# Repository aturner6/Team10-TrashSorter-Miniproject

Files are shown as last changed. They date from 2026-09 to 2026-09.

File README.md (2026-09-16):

# 03-Miniproject-2026-27

This is a repo for a multi-disciplinary mini-project for a
small team of EEs and ME. The mini-project is described in the
course assignment. You should tailor this repo based on your team
composition, roles, and the tasks at hand.

Complete the project documentation in your Miniproject repo including:
Project summary (as .md) including 
Description of device 
Photo(s) of device
Description of how to use your device
Record a link to your device in operation (< 10s) and link to file stored in your team google team folder under /video
References to any source materials adopted in the project
Project support documents
Flowcharts and or/state charts of system 
Schematic of device (no fritzing please) 
Mechanical design and CAD drawings/STLs of enclosure (if MEs on team)
Code folder including embedded code comments
Simple readme.md in each subfolder

# Project Summary 

This device is a self-contained meeting timer that runs MicroPython on a Seeed XIAO ESP32-S3. The countdown begins after the user uses two tactile buttons to choose a predetermined time (15, 20, 25, or 30 minutes). Three status LEDs (powered with PWM for a pulsating effect) show the device's current condition, and a stepper motor powers an actual clock hand that scrolls down as time passes.

# Description of the device

* Microcontroller: Seeed XIAO ESP32-S3
* Motor: 28BYJ-48 5-wire, 4-phase unipolar stepper, driven through an L293D H-bridge (wave-pulse stepping, one coil energized at a time), moving a popsicle-stick clock hand to show time remaining
* Inputs: two tactile pushbuttons (GPIO5, GPIO6)
* Outputs: three PWM-driven LEDs: red (GPIO7), blue (GPIO8), green (GPIO9), each pulsed at a ~1s duty-cycle rate

# Photo of device 
IMG_3915-preview

# How to operate
Connect and turn on the power. The blue LED will then illuminate. Select the Modes 15, 20, 25, and 30 (min) which are cycled by the left button (Button 1). The timer can be started or stopped by pressing the right button (Button 2). Timer moves clockwise (CW) until it hits the set time, then resets back to start — until Button 2 is pressed again to change mode.\
LED states: Red indicates the time is up, Green indicates the timer is active, and Blue indicates cycling (mode choose).
# Demo video
  [Demo Google Drive Video](https://drive.google.com/file/d/13cO3BlyUWwyqgb_B9XeeHkqI3Kim0GOf/view?usp=drive_link)
# References 
Reference we used for PWM LED [LinuxHint](https://linuxhint.com/pwm-esp32-micropython-thonny-ide/)

# Flowchart of the system
The flow chart of the system is [State Diagram](docs/state-flow/Mini_Project_State_Diagram.drawio.pdf) — viewable PDF.
# Schematic of the device
The schematic chart of the system is [Schematic Chart](docs/hardware/electrical/MINIPROJECTDIAGRAM.pdf) — viewable PDF.
# Mechanical design and CAS drawings/STLs of enclosure
All the mechanical designs and STL files are in [Mechanical](docs/hardware/mechanical)

# Code folder

The code folder is in [Firmware](docs/firmware)

---

## Team

| Role | Named Members |
|---|---|
| Mechanical Engineering | John |
| Electrical Engineering | Adina, Rebecca, Richard, Carlos |

---

## Repository Structure

```
.
├── firmware/          # Micro source code
├── hardware/
│   ├── electrical/    # Schematics, wiring diagrams, and BOM
│   └── mechanical/    # Enclosure CAD files and fabrication notes
└── docs/              # Project documentation 
```

---

## Hardware

| Component | Description|
|---|--- |
| Seeed XIAO ESP32-S3, pre-soldered |Microcontroller for the clock|
| Multi-color LED |Visual indicator of status|
| Breadboard |Used for connections of all other components. |
| Tactile breadboard switch |One button cycles time duration, another starts and stops|	
 | 220-ohm resistor |adds resistance to circuit|
 | Battery holder, 3x AAA cells |powers the timer|
 | Stepper motor |moves the handles in steps for timer|
 | Motor driver (L293D) |6 step control|
 | Jumper wire kit |used to connect all the components on breadboard|

---

## Team Responsibilities 
Any discipline can do any role here -- you make the assigments. 

### Mechanical oriented - John Colcha
- Design the enclosure 
- Fabricate the enclosure (3-D print or laser-cut)
- Document the assembly process 

### Electrical oriented - Carlos Rivas, Adina Turner, Richard Huang
- Produce the breadboard schematic - Adina Turner
- Summarize the bill of materials - Carlos Rivas
- Wire the circuit on the breadboard, verify that the components are assembled correctly, validate the voltage levels - Adina Turner
- Develop flowchart for the time device - Richard Huang

### Computer oriented - Rebecca Brautigam, Carlos Rivas
- Design the software based on the required functionality - Rebecca Brautigam
- Develop MicroPython code and firmware - Rebecca Brautigam
- Flash and test the firmware on the target micro - Rebecca Brautigam
- Document the project on the repo and record 10 second video - Carlos Rivas

## Deliverables

- [ ] Functional MicroPython firmware
- [ ] Completed breadboard assembly per schematic
- [ ] Fabricated and assembled enclosure (if MEs on team)
- [ ] Documentation in this repository
- [ ] Video recording demonstrating required function (stored in google drive)

## Contribution Workflow

We want each team member to contribute work products and to host these
including documentation in the repo with version control (software,
firmware, schematics, BOMs, CAD models, etc.) All can be managed in
the repo with version control.

1. Establish that each team member has properly set up Git/GitHub Desktop
2. Decompose the project into units to assign to each named team member 
3. From the team repo, create a branch from `main` named `<role>/<feature>` (e.g., `me/case`) to capture work artifacts 
4. Fetch the branch to the local laptop
5. Each team member does their work and produces work artifacts and commits these changes to the branch
6. Commit changes with descriptive messages
7. Open a pull request and request review from at least one other team member
8. Merge to main after approval

When performed properly, this workflow leads to an organized set of
work products that are developed concurrently and collaboratively with
version control. This includes the products themselves (e.g.,
firmware, CAD, schematics, etc.) and the associated documentation

Don't know how to do this? Ask your ECE teammates, GSTs, instructors, or AI. 

---

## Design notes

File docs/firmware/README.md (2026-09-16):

# Code README

## Contents
The MicroPython source for the meeting timer was uploaded to the Seeed XIAO ESP32-S3 via Thonny.

Handles the three device states (picking preset, running, time's up)
Drives the 28BYJ-48 stepper (via the L293D H-bridge) to move the clock hand as time elapses
Reads the two tactile buttons (GPIO5, GPIO6) for preset selection and start/cancel control
Drives the three status LEDs (GPIO7 red, GPIO8 blue, GPIO9 green) with PWM for the pulsing effect

Each function and the pin mapping are explained by inline comments in the code. For complete operating instructions  see the root README.md and the state chart in ../docs/.

---

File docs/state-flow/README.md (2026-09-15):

# Meeting Timer State Flow Diagram

Documents the Ready, Running, Resetting, and Finished states,
including B1 preset selection, B2 start/reset, motor return,
and LED behavior. The diagram retains its original layout,
colors, fonts, and short wording.

- [Mini_Project_State_Diagram.drawio](Mini_Project_State_Diagram.drawio) — editable diagram.
- [Mini_Project_State_Diagram.drawio.pdf](Mini_Project_State_Diagram.drawio.pdf) — viewable PDF.

## Code reference

Matches [firstDraft.py at main commit 19f7ae3](https://github.com/aturner6/Team10-TrashSorter-Miniproject/blob/19f7ae3731c46b1a6b27202ce7752f3b77c4afbd/docs/firmware/firstDraft.py), reviewed September 15, 2026.

- B1 selects the next preset only in Ready, while the hand is not returning.
- B2 starts from Ready. While running, finished, or returning, B2 resets the selected duration and returns the hand if needed.
- Resetting returns to Ready when the hand reaches its starting position. If no return is needed, reset goes directly to Ready.
- Ready and Resetting use steady blue; Running pulses green; Finished pulses red.
- At completion, the hand returns and stops, but the timer stays Finished with red pulsing until B2 resets it.
- There is no pause/resume behavior in this code.

The current code uses **15/20/25/30 seconds**; the minute-based presets are commented out. The diagram labels seconds to match the implementation. The assignment requires minutes, so the team must finalize timing and then update both diagram files if that changes.

Validation: checked state transitions against the referenced source, verified the draw.io structure, and visually checked the regenerated PDF. Physical timing, motor direction, LED wiring, and hardware behavior still require team verification.

Related task: Issue #2 — Flowstate Chart to Assess Operations.

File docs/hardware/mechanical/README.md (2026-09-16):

## CAD Models and Components README
<br> <br>
<div align="center">

### Ideation and Initial Sketches
Before moving into SolidWorks, the initial concepts and dimensions were mapped out by hand. These sketches highlight the early brainstorming process for the enclosure's overall footprint, internal clearances for the breadboard, and the structural ideas for the stepper motor holder and tactile button attachments. 

<br>



<br>
<br>



</div>

<div align= "center">
  
  <br> <br>
  
## From Concept to CAD: SolidWorks Implementation
  <br> <br>
Using the dimensions and concepts mapped out in the initial sketches, the final components were modeled in SolidWorks. The isometric views below show the exact geometry used to 3D print the enclosure, incorporating the required motor mounts and external USB-C pathways.

<br>


<br>
<br>
This component serves as the enclosure lid and the timer's primary display surface, featuring a central clearance hole for the motor shaft and the indicator assembly.
<br>
<br>
</div>

<div align= "center">

<br> 
<br>
This forms the primary physical housing for the microcontroller, driver board, and wiring. It features a specific rectangular cutout on the side wall to provide the required pathway for the external USB-C cable
<br> 
<br>
</div>

# Figure A:
<div align+"center">

<br>
<br>

</div>

# Figure B:
<div align="center">

</div>

<div align="center">
<br>
As shown in Figures A and B, these parts serve as the physical interface for the timer. This component acts as the outer structural attachment for the tactile button. It mounts to the main enclosure and provides a precise  guide for the button stud to travel through smoothly.
<br>
<br>
</div>

<div align="center">

<br>
<br>
This bracket secures the stepper motor in place. Its side tabs allow it to be fastened firmly to the enclosure, fulfilling the required physical motor mount specification.
<br>
<br>
</div>

<div align="center">

<br>
<br>
The cylindrical sleeve features an internal keyed geometry design to mate with the flat edges of the stepper motor's shaft, ensuring the rotational torque is transferred to the clock hand without slipping.
<br>
<br>
</div>

<div align="center">

<br>
<br>
This is the physical plunger that the user presses. It rests inside the housing and makes direct contact with the tactile buttons on the board to input the 15, 20, 25, or 30-minute timer preset.
<br>
<br>
</div>

For details of the project, see the root README.md.

---

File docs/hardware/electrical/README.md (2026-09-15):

# Project Documentation

Electrical design files for the meeting timer.
Schematic of the XIAO ESP32-S3, L293D H-bridge driver, stepper motor, LEDs, and buttons

Bill of Materials (see xlsx file for links)

| Qty | Component | Part No. | Unit Price | Total | Vendor |
|---|---|--- | --- | --- |----- |
| `6 (per student)` | Seeed XIAO ESP32-S3, pre-soldered |1597-102010634-ND|$8.49|$50.94|Digikey|
| `1 (per student)` | Multi-color LED |1830-1014-ND|$0.59|$0.59|Digikey|
| `1 (per student)` | Breadboard |1188-BREADBOARD-1-ND|$2.05|$2.05|Digikey|
| `2 (per student)` | Tactile breadboard switch |EG2533CT-ND|	$0.20|$0.40|Digikey|
| `3 (per student)` | 220-ohm resistor |CF14JT220RCT-ND|$0.013|$0.04|Digikey|
| `1 (per team)` | Battery holder, 3x AAA cells |1428-1151-ND|$1.95|$1.95|Digikey|
| `1 (per team)` | Stepper motor |1188-SM-5VDC-DRV-ND|$2.93|$2.93|Digikey|
| `1 (per team)` | Motor driver (L293D) |5536-L293DN-ND|$1.73|$1.73|Digikey|
| `1 (per team)` | Jumper wire kit |BKWK-3-ND|$5.60|$5.60|Digikey|
| Total |  |||$66.24||

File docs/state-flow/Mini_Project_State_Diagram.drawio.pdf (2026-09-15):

EC463 / MINI-PROJECT

# Meeting timer — State diagram

Two buttons • Presets: 15 → 20 → 25 → 30 → 15 seconds (current code)

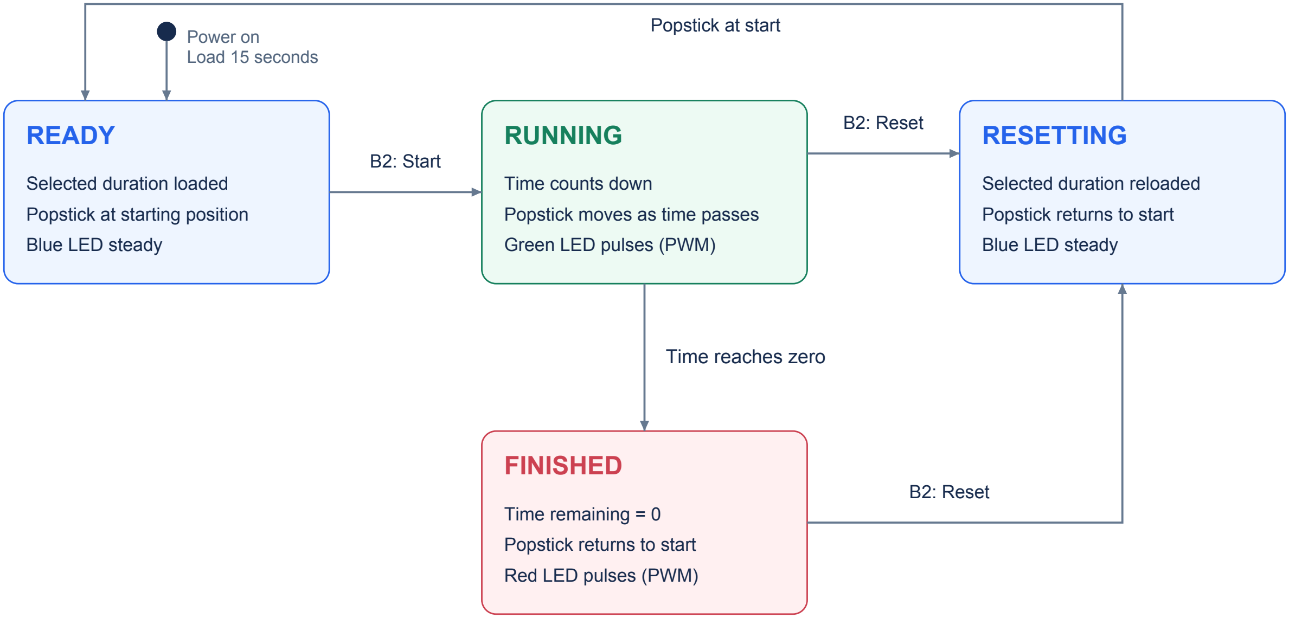
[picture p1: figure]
READY; Selected duration loaded; Popstick at starting position; Blue LED steady; RUNNING; Time counts down; Popstick moves as time passes; Green LED pulses (PWM); RESETTING; Selected duration reloaded; Popstick returns to start; FINISHED; Time remaining = 0; Red LED pulses (PWM); Power on Load 15 seconds; B2: Start; B2: Reset; Popstick at start; Time reaches zero

B1: MODE — applies in Ready only

### Next preset → reload time → stay Ready (no popstick movement)

Buttons: B1 selects only in Ready. B2 resets during return; if the hand is already at start, reset goes straight to Ready.

Finished: hand returns, then stops; red keeps pulsing until B2 resets. Startup: hand assumed at start.

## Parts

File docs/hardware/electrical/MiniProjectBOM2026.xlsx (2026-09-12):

Index | Distribution | Description | Part No. | QTY | Unit | Total | Vendor | URL | Alt source | Alt URL
1 | Per student | Seeed XIAO ESP32S3 pre-soldered | 1597-102010634-ND | 6 | 8.49 | 50.94 | Digikey | https://www.digikey.com/en/products/detail/seeed-technology-co-ltd/102010634/26553885 | Seeed (CA) | https://www.seeedstudio.com/Seeed-Studio-XIAO-ESP32S3-Pre-Soldered-p-6334.html
2 | Per student | Multi-color LED | 1830-1014-ND | 1 | 0.59 | 0.59 | Digikey | https://www.digikey.com/en/products/detail/inolux/INL-5TB4URGB60/7604616
3 | Per student | Breadboard | 1188-BREADBOARD-1-ND | 1 | 2.05 | 2.05 | Digikey | https://www.digikey.com/en/products/detail/olimex-ltd/BREADBOARD-1/21662422
4 | Per student (2) | Tactile breadboard switch | EG2533CT-ND | 2 | 0.20452 | 0.40904 | Digikey | https://www.digikey.com/en/products/detail/e-switch/TL59AF160Q/390534
5 | Per student (3) | Resistors 220 ohm | CF14JT220RCT-ND | 3 | 0.01258 | 0.03774 | Digikey | https://www.digikey.com/en/products/detail/CF14JT220R/CF14JT220RCT-ND/1830334
6 | Per team | Battery holder 3 AAA cells | 1428-1151-ND | 1 | 1.95 | 1.95 | Digikey | https://www.digikey.com/en/products/detail/adafruit-industries-llc/727/5353611
7 | Per team | Stepper motor | 1188-SM-5VDC-DRV-ND | 1 | 2.93 | 2.93 | Digikey | https://www.digikey.com/en/products/detail/olimex-ltd/SM-5VDC-DRV/21662223
8 | Per team | Motor driver | 5536-L293DN-ND | 1 | 1.73 | 1.73 | Digikey | https://www.digikey.com/en/products/detail/taejin/L293DN/22237446
9 | Per team | Jumper wire kit | BKWK-3-ND | 1 | 5.6 | 5.6 | Digikey | https://www.digikey.com/en/products/detail/global-specialties/WK-3/5231342
 |  | Total |  |  |  | 66.23678

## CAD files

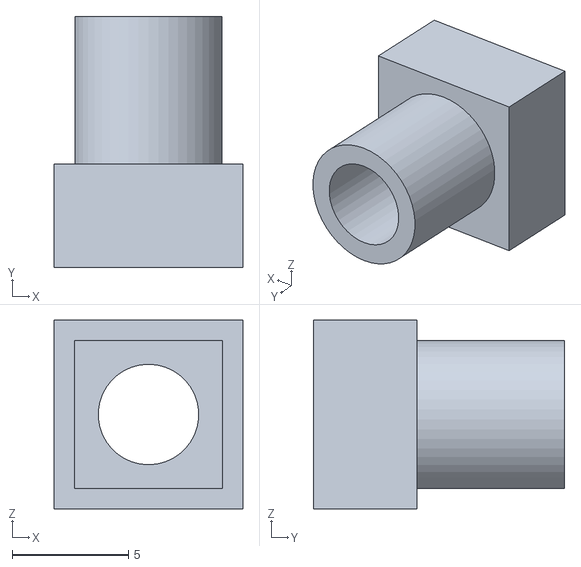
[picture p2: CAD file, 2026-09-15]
docs/hardware/mechanical/button attachment v3.STL
8.13 x 10.8 x 8.13

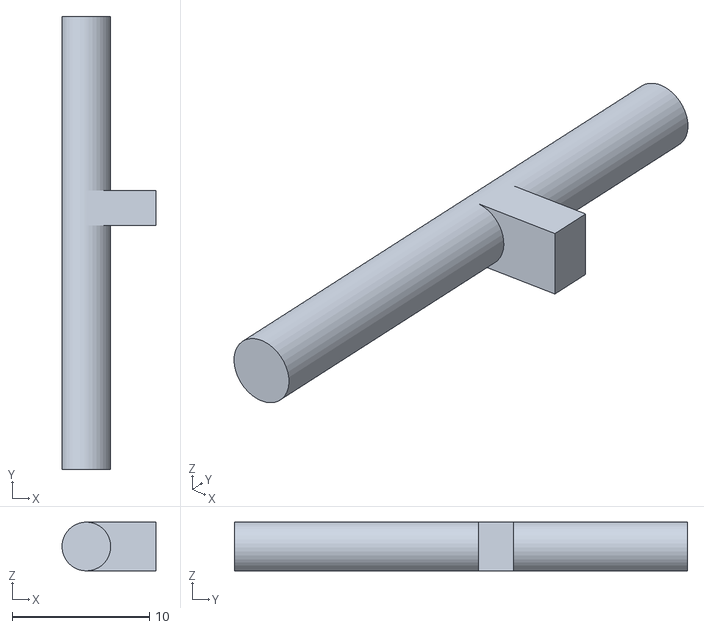
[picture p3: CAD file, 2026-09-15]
docs/hardware/mechanical/button stud V3.STL
6.86 x 33.0 x 3.56

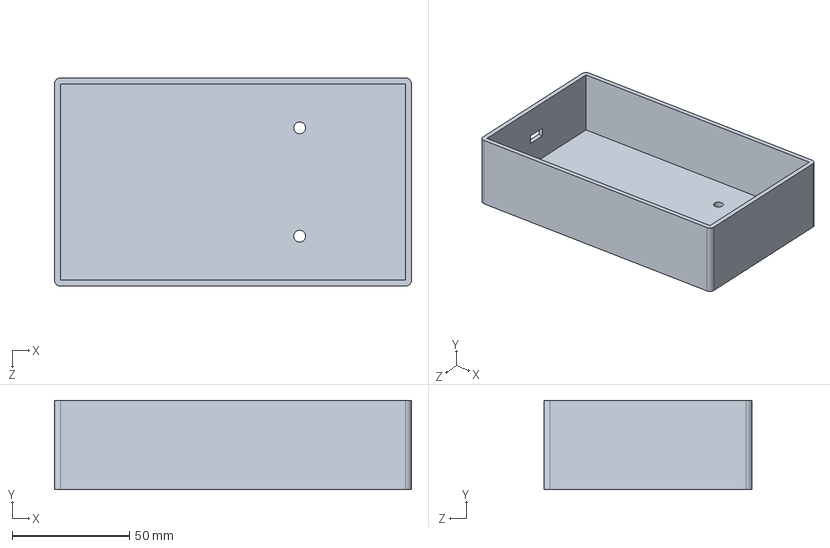
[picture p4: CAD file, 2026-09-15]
docs/hardware/mechanical/Miniproject_enclosure V3.SLDPRT
152.4 x 38.1 x 88.9 mm

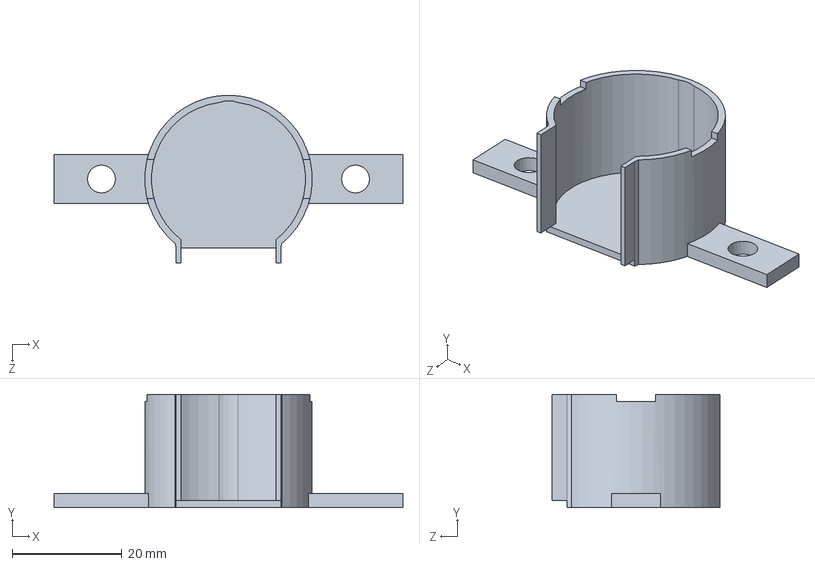
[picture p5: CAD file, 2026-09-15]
docs/hardware/mechanical/stepper motor holder.SLDPRT
63.5 x 20.6 x 30.5 mm

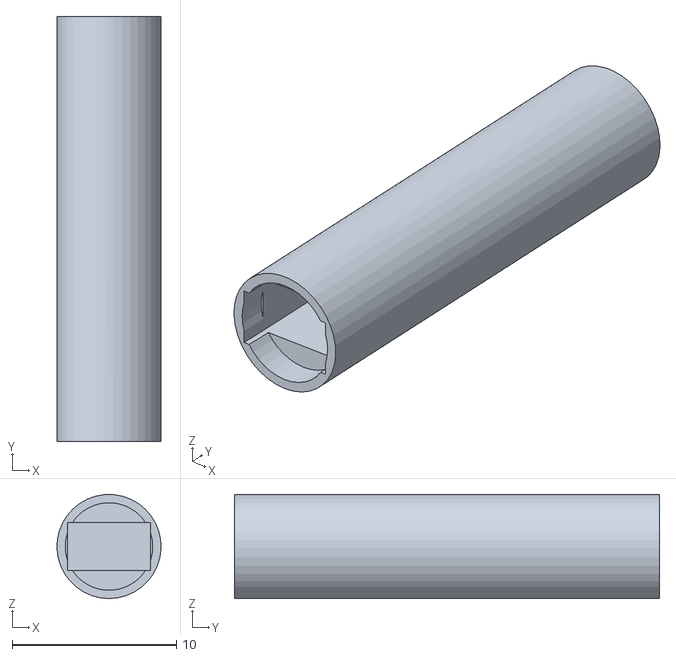
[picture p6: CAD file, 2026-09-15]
docs/hardware/mechanical/steppermotor attachment v3.STL
6.34 x 25.9 x 6.35

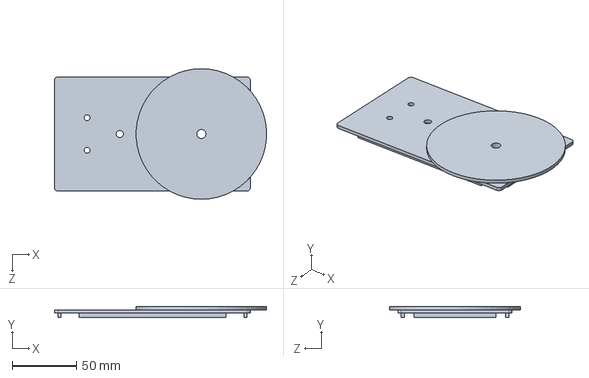
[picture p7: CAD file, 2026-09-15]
docs/hardware/mechanical/lid_miniproject v3.SLDPRT
165.0 x 8.26 x 101.6 mm

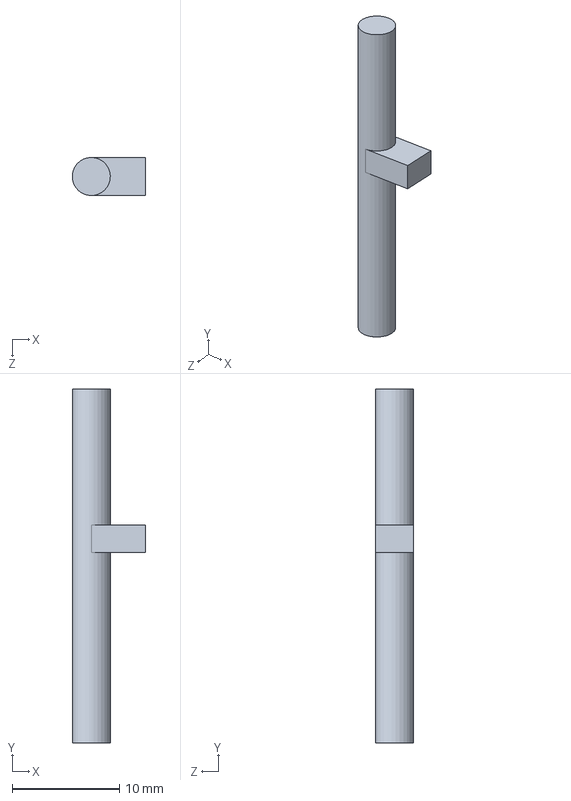
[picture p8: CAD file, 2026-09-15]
docs/hardware/mechanical/button stud.SLDPRT
6.86 x 33.0 x 3.56 mm

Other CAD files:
docs/hardware/mechanical/button attachment.SLDPRT
docs/hardware/mechanical/stepper motor holder v4.STL
docs/hardware/mechanical/steppermotor attachment.SLDPRT
docs/hardware/mechanical/Miniproject_enclosure v3.STL
docs/hardware/mechanical/lid_miniproject v3.STL

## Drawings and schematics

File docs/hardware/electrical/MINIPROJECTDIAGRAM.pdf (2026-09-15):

220Ω

# ESP32-S3 L293D DRIVER

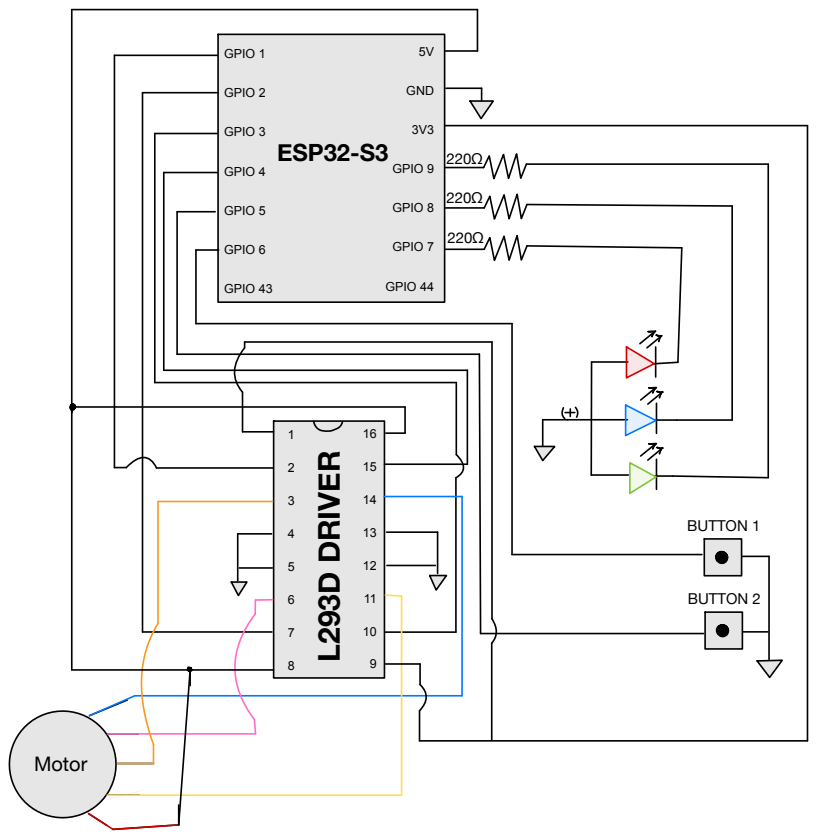
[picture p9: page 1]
GPIO 1; GPIO 2; GPIO 3; GPIO 4; GPIO 5; GPIO 6; GPIO 43; GND; GPIO 9; GPIO 8; GPIO 7; GPIO 44; Motor; BUTTON 1; BUTTON 2

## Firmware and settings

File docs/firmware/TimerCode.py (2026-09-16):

from machine import Pin, PWM
import time

#used as guides:
#pwm: https://linuxhint.com/pwm-esp32-micropython-thonny-ide/

#inputs
butt1 = Pin(5, Pin.IN, Pin.PULL_UP) #cycle thru 15 20 25 30
butt2 = Pin(6, Pin.IN, Pin.PULL_UP) #start/reset
#Pin.PULL_UP is bc there is no resistor attached
#not press = 1
#pressed = 0

#leds
red = PWM(Pin(8)) #timer finished
green = PWM(Pin(7)) #timer working
blue = PWM(Pin(9)) #waiting mode

Frequency = 1000 #0 to 78125, website uses 5k

red.freq(Frequency)
blue.freq(Frequency)
green.freq(Frequency)

#motor configuration
STEPS_PER_REVOLUTION = 2048 # like variable says, number of steps to complete 1 revolution

#motor control pins
IN1 = Pin(1, Pin.OUT)
IN2 = Pin(2, Pin.OUT)
IN3 = Pin(3, Pin.OUT)
IN4 = Pin(4, Pin.OUT)

#wave stepping sequence
step_sequence = [
    (1, 0, 0, 0),   # Coil 1 - orange
    (0, 0, 1, 0),   # Coil 2 - pink
    (0, 1, 0, 0),   # Coil 3 - yellow
    (0, 0, 0, 1)    # Coil 4 - blue
]
# since we want to do it in waves, we have to charge it one at a time to use it, moving one coil a little at a time

step_number = 0 #keep track of step number, will change thruought

#functions for LED
def led_off(): # led off = led off
    red.duty(0)
    blue.duty(0)
    green.duty(0)

#blue = waiting to start, can change timer mode
#green = timer is active
#red = timer ended, reseting
def set_blue(): #only blue is on, fully on
    red.duty(0)
    blue.duty(1023)
    green.duty(0)
#blue is on the whole time bc it serves as a waiting mode

def set_green(brightness): # have green be whatever brightness is set to
    red.duty(0)
    blue.duty(0)
    green.duty(brightness)
#green pulses bc it's "active"

def set_red(brightness): # have red be whatever brightness is set to
    red.duty(brightness)
    blue.duty(0)
    green.duty(0)
#red pulses to alert the user

#reset LED pulsing
def reset_pulse():
    global pulse_brightness
    global pulse_direction

    pulse_brightness = 0 #start with led turned off
    pulse_direction = 1 #1 means the brightness increases

#functions for stepper
def step_motor(direction): #direction 1 -> forward, -1 -> backward
    global step_number
    
    sequence = step_sequence[step_number] #get pattern from stepping sequence
    
    #pattern order, send it to four motor control pins
    IN1.value(sequence[0])
    IN2.value(sequence[1])
    IN3.value(sequence[2])
    IN4.value(sequence[3])

    #move to next step
    step_number += direction
    step_number = step_number % 4
    #%4 is a remainder of 4 and creates a repeating pattern of 0 1 2 3 0 1 2 3
    
#turns off all coils
def motor_off():
    IN1.value(0)
    IN2.value(0)
    IN3.value(0)
    IN4.value(0)


#timer stuff
presets = [ #options for timers
    #these were tester values, 15-30 seconds
#     15,
#     20,
#     25,
#     30
    15 * 60,    # 15 minutes
    20 * 60,    # 20 minutes
    25 * 60,    # 25 minutes
    30 * 60     # 30 minutes
]

full_rev = 30 * 60 #time to get a full turn, * 60 for mins

#keeping track of which timer is active, 0 - 15, 1 - 20, 2 - 25, 3 - 30
preset_number = 0
selected_time = presets[preset_number]
remaining_time = selected_time #time left on timer

#running = running, timer is counting
# finished = timer ended
#returning = timer is moving back to orig position
running = False
finished = False
returning = False

#functions for clockhand
steps_taken = 0
last_step_time = time.ticks_ms() # stores last time motor moved
start_time = time.ticks_ms() # stores when timer started
last_return_step_time = time.ticks_ms() # lat time motor was moved while returning

def get_step_interval():
    # Time for one complete revolution divided by number of steps
    return (full_rev * 1000) / STEPS_PER_REVOLUTION

def get_target_steps(): #calcs motor steps to time
    return int((selected_time / full_rev) * STEPS_PER_REVOLUTION)


#button setup
last_butt1 = 1
last_butt2 = 1
last_butt_time = time.ticks_ms() #debounces basically
BUTT_DELAY = 200 # min time b/w presses

#led pulsing
pulse_brightness = 0
pulse_direction = 1

last_pulse_time = time.ticks_ms() #stores last time led brightness changed

def update_pulse(color): #led slowly brightens and dims

    global pulse_brightness
    global pulse_direction
    global last_pulse_time

    current_time = time.ticks_ms()

    #change brightness every 5 ms
    if time.ticks_diff(current_time, last_pulse_time) >= 5:

        last_pulse_time = current_time
        
        #incr or decr brightness
        pulse_brightness += pulse_direction * 10
        
        #if max brightness, go dimmer
        if pulse_brightness >= 1023:
            pulse_brightness = 1023
            pulse_direction = -1
        #if min brightness, go brighter
        if pulse_brightness <= 0:
            pulse_brightness = 0
            pulse_direction = 1
        #sets green @ brightness level
        if color == "green":
            set_green(pulse_brightness)
        #sets red
        elif color == "red":
            set_red(pulse_brightness)

#timer

def reset_timer():

    global remaining_time
    global running
    global finished
    global returning
    global steps_taken
    global step_number
    global last_step_time
    global start_time
    global last_return_step_time
    
    #put remaining time back to selected time option
    remaining_time = selected_time
    
    #stop timer since we are resetting it
    running = False
    finished = False

    #if motor moved, move it back to starting position
    if steps_taken > 0:
        returning = True
        last_return_step_time = time.ticks_ms() # when return movement started

        #resetting LED
        set_red(1023)

    else: #at start, dont move it
        returning = False
        step_number = 0
        motor_off()

        #waiting LED
        set_blue()

    #reset LED pulse
    reset_pulse()

    last_step_time = time.ticks_ms()
    start_time = time.ticks_ms()

#init

set_blue() #blue is on when turned on
reset_pulse()
motor_off()

#actual program

while True:

    current_time = time.ticks_ms()

    #button 1: cycle thru options
    butt1_state = butt1.value()
    if butt1_state == 0 and last_butt1 == 1: #debouncing more

        #only can change if preset mode is active
        if not running and not finished and not returning:
            preset_number += 1 # move to next preset option
            if preset_number >= len(presets): # cycle back to first preset when preset list is exhausted
                preset_number = 0
            selected_time = presets[preset_number] #get new selected time
            remaining_time = selected_time #reset remaining time to new option in case it held old one
            finished = False
            print( #print to thonny just in case
                "Timer:",
                selected_time //60, #divide to get minutes
                "minutes"
            )
            set_blue()

    last_butt1 = butt1_state # remember current state

    #button 2: start/reset
    butt2_state = butt2.value()
    if butt2_state == 0 and last_butt2 == 1:

        #debouncing
        if time.ticks_diff(current_time, last_butt_time) > BUTT_DELAY:
            last_butt_time = current_time

            #if timer is running OR finished, reset
            if running or finished or returning:
                reset_timer()
                print("Timer reset")

            #otherwise start timer
            else:
                running = True
                finished = False
                returning = False

                #reset green LED pulse
                reset_pulse()
                last_step_time = current_time
                start_time = current_time
                print("Timer started") #for testing tbh

    last_butt2 = butt2_state

    #if timer running
    if running:

        #pulse green led
        update_pulse("green")

        #move hand
        elapsed_seconds = time.ticks_diff(current_time, start_time) / 1000

        #calculate how many steps the hand should have taken by now
        target_steps = int((elapsed_seconds / full_rev) * STEPS_PER_REVOLUTION)

        if steps_taken < target_steps: #if not at correct step, move it forward
            step_motor(1)
            steps_taken += 1

        #check remaining time
        remaining_time = selected_time - elapsed_seconds

        #timer finished
        if elapsed_seconds >= selected_time: #reseting !
            remaining_time = 0
            running = False
            finished = True
            returning = True

            #reset red LED pulse
            reset_pulse()
            set_red(1023)
            last_return_step_time = current_time
            print("TIMER FINISHED!")

    #timer finished
    elif finished:

        #pulse red LED
        update_pulse("red")

        #return hand to starting position
        if returning:

            if steps_taken > 0: #if not back at starting position
                
                #moving it back !!!
                if time.ticks_diff(current_time, last_return_step_time) >= 1: #smaller number = faster
                    last_return_step_time = current_time
                    step_motor(-1) # move 1 step back
                    steps_taken -= 1 #count that ^

            else: #made it to start
                returning = False
                step_number = 0
                motor_off()

                #waiting LED
                set_blue()

    #waiting for timer
    else:

        #blue LED only when NOT resetting
        if not returning:
            set_blue()

        #return hand to starting position
        if returning:

            if steps_taken > 0: #checking for steps leftover
                
                
                #move motor backward quickly
                if time.ticks_diff(current_time, last_return_step_time) >= 1:
                    last_return_step_time = current_time
                    step_motor(-1)
                    steps_taken -= 1

            else:
                returning = False
                step_number = 0
                motor_off()

                #waiting LED
                set_blue()

    #lil delay
    time.sleep_ms(5)

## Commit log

2026-09-11 Add timer state flow diagram for issue #2
2026-09-15 Mechanical Parts For The Enclosure
    These are the STL and the SolidWorks parts files for the habitat/enclosure
    [Miniproject_enclosure v3.STL, Miniproject_enclosure.SLDPRT, button attachment v3.STL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]
2026-09-15 Mechanical Parts for Enclosure
    [Miniproject_enclosure V3.SLDPRT, Miniproject_enclosure v3.STL, button stud V3.STL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]
2026-09-15 Align state diagram with current timer firmware
2026-09-16 Update README.md device photo
